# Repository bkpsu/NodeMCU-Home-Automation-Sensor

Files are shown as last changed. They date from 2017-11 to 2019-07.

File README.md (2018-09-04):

# NodeMCU-Home-Automation-Sensor (a.k.a. The Kube)

# IMPORTANT  
Going forward, the Kube sensor will be using the ESPEasy (https://github.com/letscontrolit/ESPEasy) project as firmware. The work done by the ESPEasy team is great and allows me to leverage all of their supported sensors, focusing on hardware development and not wasting redundant effort on software. 

In order to support the OLED screen in ESPEasy (and avoid having non-standard configuration), it is important to move the D9/D10 pins used in the I2C configuration to D3/D4 (SDA/SCL).

# 

Code for Thingiverse item https://www.thingiverse.com/thing:2539897 (The Kube - a NodeMCU/DHT22 based MQTT temp/humidity sensor with local OLED display)

Note: The parts list I posted on the Thingiverse site (and below) contains affiliate links to Amazon. These are the parts I've used/tested in building my sensors, and if you wish to support my designs, please go ahead and use them to order parts. Thank you and enjoy!

Demo & Overview (https://www.youtube.com/watch?v=VefbT6RuT-4)

# Parts List

  *3D printed enclosure (https://www.thingiverse.com/thing:2539897)  
  *OLED screen (http://amzn.to/2xR4iQP) - I2C recommended  
  *NodeMCU breakout board (https://www.tindie.com/products/11677/)  
  *NodeMCU ESP8266 dev board v0.9 (http://amzn.to/2hd6RJk) or 1.0 (http://amzn.to/2ymAkak).  
  *DHT-22 sensor (http://amzn.to/2ymmODK)  
  *headers (http://amzn.to/2fNe81C)  
  *solid hook-up wire, 22awg (https://amzn.to/2voliAb)

# Build Procedure

Initial Build

1. Print enclosure and cover
2. Solder left/right inner headers onto the OSHPark carrier board (15 pins each)
3. Solder DHT22 sensor onto board, with openings facing out
4. Stick NodeMCU board onto carrier board, USB connector facing opposite from DHT22
5. De-pin OLED screen (cut the black plastic holding pins together, remove pins one by one) <- alternatively, you can use breadboard wires (http://amzn.to/2fDGqeJ) with connectors on each end if you don't want to de-pin, but you'll have to bend the OLED screen pins to the side.
6. Cut seven (7) short (~2 inch) lengths of hook-up wire and strip on each end.
7. Connect/solder OLED screen to carrier board as follows:

For SPI OLED:

| Board | Wire Color | OLED  |  
|:---:|:-----:|:-----:|
| 3v3 |  Red | VCC| 
| Gnd |  Black  | Gnd |  
| D10 |  Orange |  Res |  
| D9 |  Gray  |  DC  |  
| D8 |  White  |  CS  |  
| D7 | Yellow  | D1  |  
| D5 | Brown  |  D0  |  

For I2C OLED:



| Board | Wire Color | OLED  |  
|:---:|:-----:|:-----:|
| 3v3 |  Red | VCC| 
| Gnd |  Black  | Gnd | 
| D4 | Blue | SCL |
| D3 | Green | SDA |  

Final Assembly:

1. Stick OLED screen onto mounting posts (ensuring the screen is within the enclosure opening) and use a soldering iron to melt the posts over it.

2. Put NodeMCU carrier board in, ensuring it fits snugly (DHT sensor is tightly within its opening, USB connector is visible)

3. Put enclosure cover on, and secure with small screws (or glue in place)

Hardware Build Video (https://www.youtube.com/watch?v=fA91LcJRbhI)

**Note** Since the video was posted, I've switched to using pins D3/D4 as SCL/SDA for the I2C OLED screen, instead of D9/D10. Please connect the OLED as per the I2C table above!

# Program sensor

Just follow the video below to program the sensor in Arduino IDE using the code provided in this repository.

**Note** Since this video was posted, I updated the code to use the WiFiManager library and allow the ESP8266 to create its own access point (AP). This means you no longer have to specify the Wifi SSID or password in the code. Simply load the code onto the ESP8266, power it on, and look for it in your phone's WiFI settings. Once you connect to it, it will handle connecting to your home's Wifi via a web-based process. This takes one step away from the programming procedure, but please still watch the video below to understand how the different options affect the sensor's operation.

**Note 2** Make sure you have the following Arduino Board files and Libraries installed in order to avoid compilation/runtime errors:  
**Board Files**  
ESP8266 by ESP8266 Community (v 2.4.1 or higher)  
**Libraries**  
Adafruit Unified Sensor by Adafruit (v 1.0.2 or higher)  
ArduinoOTA by Ivan Grokhotkov and Miguel Angel Ajo (v 1.0.0 or higher)  
DHT Sensor Library by Adafruit (v 1.3.0 or higher)  
ESP8266 and ESP32 Oled Driver for SSD1306 Display by Daniel Eichhorn, Fabrice Weinberg (v 4.0.0 or higher)  
ESP8266mDNS  
ESP8266WiFi by Ivan Grokhotkov (v 1.0.0 or higher)  
PubSubClient by Nick O'Leary (v 2.6.0 or higher)  
WiFiManager by tzapu (v 0.12.0 or higher)  

**Note 3** As of 9/3/2018, work on this software project is halted, in favor of using ESPEasy as the firmware. I will leave the project file as-is, in case you don't want to move to ESPEasy, but I recommend using ESPEasy since it's actively developed and supports many more sensors already.

Arduino Programming Video (https://img.youtube.com/vi/uDsnqi1Vl4U)

# Connect to openHAB and Calibrate

Now that we have the sensor built and running, we have to connect it to openHAB - watch the following video on how to do that using the provided MQTT topics, and how to calibrate the sensor by charting its readings against another sensor, thermostat, temperature gauge, etc..

openHAB connection video

That's it! Enjoy the sensor and please contribute to its further design by opening new issues or comments in this repository!

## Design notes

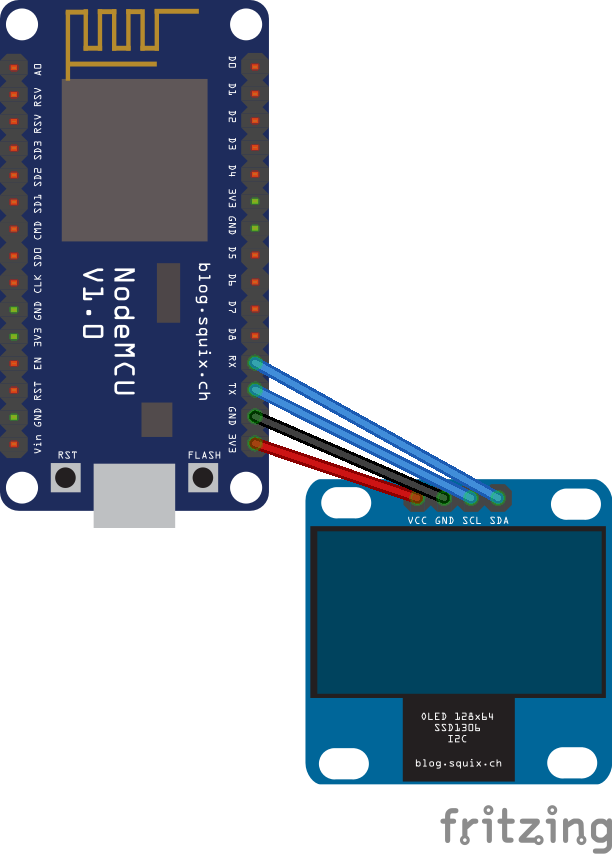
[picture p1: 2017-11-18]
OLED I2C Hookup.png

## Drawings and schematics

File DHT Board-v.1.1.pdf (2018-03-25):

# 15 DHT

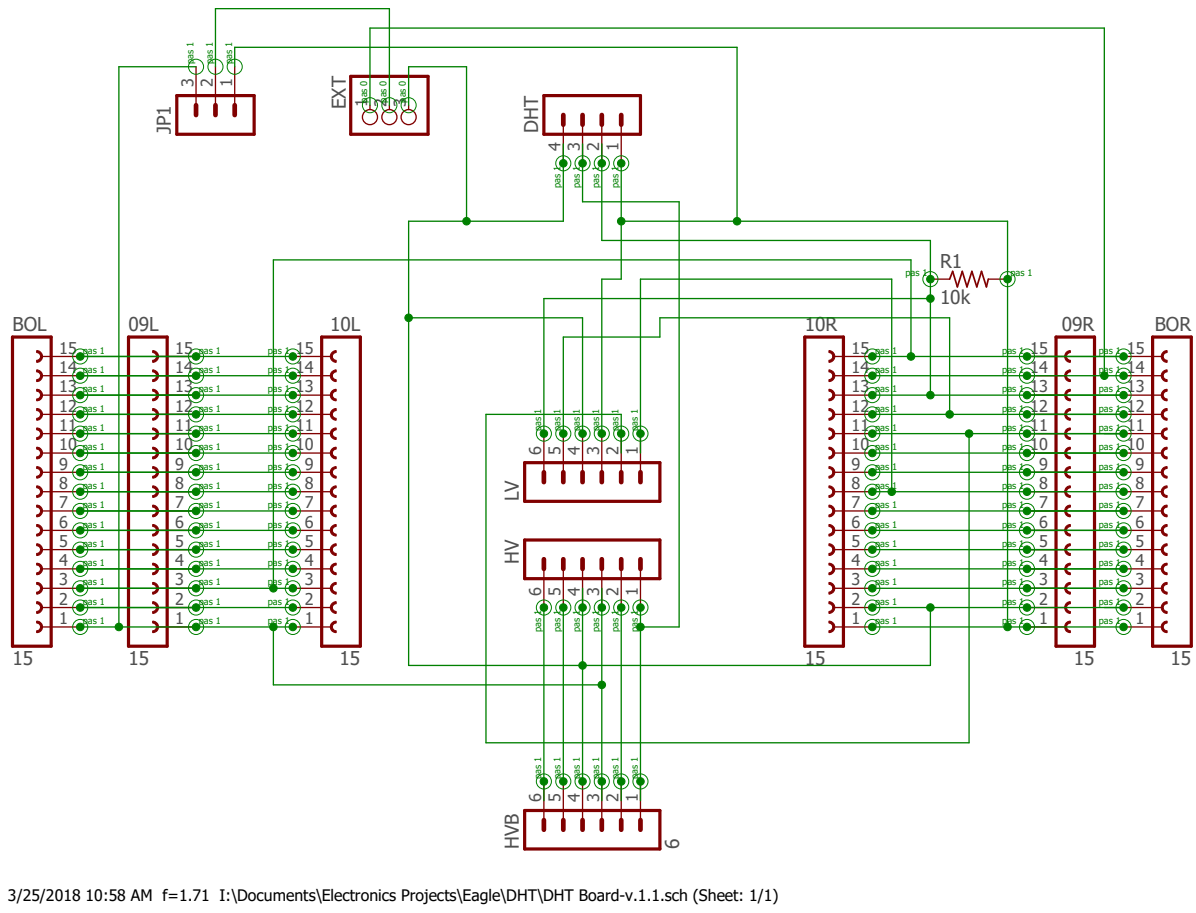
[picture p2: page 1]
BOR; BOL; 1 HVB; 15 EXT 1; pas 1; pas 1 pas 1; pas 0; pas 0 pas 1

3/25/2018 10:58 AM f=1.71 I:\Documents\Electronics Projects\Eagle\DHT\DHT Board-v.1.1.sch (Sheet: 1/1)

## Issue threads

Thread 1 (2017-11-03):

Celcius

samabsalom, 2017-11-03:
great project thanks! however, could you help me turn the display into Celsius, please?
Sam

bkpsu, 2017-11-05:
@samabsalom I just committed a new version of the code, with a new compiler directive (#CELSIUS). I've tried it and it appears to work. Test it and let me know, thanks for submitting the issue!

samabsalom, 2017-11-06:
Hello,
Thanks for getting back to me so quick. started fresh with your new code and ran into problems compiling.
it said
 C:\Users\Sam_A\Desktop\NodeMCU-Home-Automation-Sensor-master\ESP8266-PIR-OLED-Arduino\ESP8266-PIR-OLED-Arduino.ino: In function 'void loop()':

ESP8266-PIR-OLED-Arduino:243: error: too few arguments to function 'void drawDHT(float, float, float, float)'

       drawDHT(h,t,f);

                    ^

C:\Users\Sam_A\Desktop\NodeMCU-Home-Automation-Sensor-master\ESP8266-PIR-OLED-Arduino\ESP8266-PIR-OLED-Arduino.ino:136:6: note: declared here

 void drawDHT(float h, float t, float f, float p)

      ^

Multiple libraries were found for "SSD1306.h"
 Used: C:\Users\Sam_A\Documents\Arduino\libraries\ESP8266_Oled_Driver_for_SSD1306_display
 Not used: C:\Users\Sam_A\Documents\Arduino\libraries\arduino_941869
exit status 1
too few arguments to function 'void drawDHT(float, float, float, float)'

if I removed the ,float p and the ,p from both lines it compiled and uploaded to my board and output a sensible temperature

Thanks very much! I'm going to try to add OTA to it. I'll let you know how I get on!

bkpsu, 2017-11-07:
Ah, my mistake! I am working on incorporating a pressure sensor input, and I uploaded half-finished code for that. Line 243 is missing the pressure input.

OTA would be cool and very useful! If you do end up adding it/making it work, l would appreciate if you forked/added a pull request! I will open a new issue for that.

Closed 2017-11-07.

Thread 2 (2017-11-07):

Add OTA firmware update

bkpsu, 2017-11-07:
It would be great to have the ability to OTA update these sensors wherever they are installed around the house.

samabsalom, 2017-11-07:
Just sent a PR for this. Hope it works for you too. I tried to do it in a similar way to the rest of your file

Sam

bkpsu, 2017-11-08:
#5 will fix this.

bkpsu, 2017-11-08:
Implemented, using @samabsalom  #5

Closed 2017-11-08.

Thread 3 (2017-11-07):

Add pressure sensor support

bkpsu, 2017-11-07:
Looking at MPXV7002 differential pressure sensor, for possible use as a static pressure monitor for HVAC systems. Kube would monitor/report static pressure (and possibly calculate CFM) to HA system, for coordination with automated (or manual) register control, to avoid over pressurizing the HVAC system.

MPXV7002 is an analog (5V) sensor, so work needs to be done to test reading the analog input into the ESP8266's ADC input and make sure resolution/readings make sense.

bkpsu, 2018-04-25:
Latest commit adds software support for the MPXV7002 sensor, but initial testing with the sensor (attached in series with a 180Kohm resistor to drop the 0-5V to 0-1V ADC input) shows bad fluctuation of input even at static pressure (both ports on the sensor tied together). Need to look at using external, lower-range sensor with I2C input most likely, or figure out what's causing the erroneous readings (voltage supply or bad sensor?)

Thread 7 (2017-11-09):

Add Frizing wiring diagrams to Readme

bkpsu, 2017-11-09:
Readme file could use a graphical representation of wiring of the OLED screen (both SPI and I2C versions), as well as external sensor wiring setup.

(Eventually, I think the more technical documentation has to be moved into the Wiki instead of being in the Readme).

bkpsu, 2018-04-25:
Closing, as I rewrote the readme with full formatting and links to the YT videos describing build/setup, and added Fritzing diagram for I2C hookup.

Closed 2018-04-25.

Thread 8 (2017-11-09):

Split out configuration into separate source file

bkpsu, 2017-11-09:
With the number of modes available or planned (local/remote, screen/no screen, motion, temp, pressure, LED), the configuration of the sensor is starting to get unwieldy. I think it would be a good idea to split out the config into a separate .h file (config.h), which would only have the #define statements and MQTT/Wifi config (basically, settings the user is expected to change prior to flashing).

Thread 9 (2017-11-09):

Simplify configuration

bkpsu, 2017-11-09:
While it's good to allow all the different permutations of #define options, I think that also makes things confusing (especially as the number of #define options grows). Perhaps there is a way to simplify that, by making some preconfigured "models" of the sensor, with the correct options already set in the header file (once #8 is completed). Or, the other thought is to minimize the number of options available, keeping only the ones that require a choice (Local/Remote, OLED_SPI/I2C, OTA/no OTA, F/C, ...), while the optional sensor/display options will always be turned on (and fail out if unavailable).

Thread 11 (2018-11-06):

pcb

martymoose, 2018-11-06:
hi had a look at your great project
went to buy a pcb on tinde
they wont ship to australia
have you released the board files so i can get one printed here
cheers

bkpsu, 2018-11-08:
NodeMCU v1.2 done and project posted to this repository: https://github.com/bkpsu/NodeMCU-Breakout-Board

I've ordered some test boards from PCBWay, but I'm 99% sure there shouldn't be any problems :)

Closed 2018-11-08.

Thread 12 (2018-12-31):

ESPeasy configuration

stratosgear, 2018-12-31:
Did I miss somewhere posted instructions on how you setup ESPEasy with your configuration?

Or I will have to piece together how to setup everything from the ESPEasy wiki pages?

Thanks for providing such a nice inspiration for aroom multisensor.

bkpsu, 2019-01-02:
I haven't had a chance to update the repository with a generic/sample configuration file yet, or make a how-to video on configuring ESPEasy on the sensor (though I did touch on the topic during one of my recent live streams here: https://youtu.be/OtSEf2v0Zeg ).

While I work on that, I've saved an existing configuration from one of my home sensors, attached here:

[config_Kitchen_U0_Build20103_201919.zip](https://github.com/bkpsu/NodeMCU-Home-Automation-Sensor/files/2719729/config_Kitchen_U0_Build20103_201919.zip)

You should be able to upload this to your Kube, change the Wifi SSID/Password (in the Config tab), fix the IP range settings, and MQTT broker settings in the "Controllers" section. Let me know if this works.

Thanks for the catch, and I'm happy to see my project has been an inspiration!!

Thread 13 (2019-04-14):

Possible temp offset clac issue?

testack18, 2019-04-14:
Hi BK,

Thanks for sharing your excellent project!
I run into an issue and I'm not sure if it is related to the code or whatever. Please take in consideration that I'm newbie in arduino ide and IOT things so this could be easily my fault.

So the issue is it seems the temp offset is not counted as it should on my device. If I print the value to serial before and after the calculation it shows the exact same value:

```
        Serial.println(String(t));
        t = t + ((5 / 9) * temp_offset);
        Serial.println(String(t));

```

Both has at the moment 27 which is much over as it in reality.
I made some test on the code and it seems int devided by int is int (in this case 0) and 0*temp_offset is 0.

So what about 5.0 / 9.0 ?

Thanks in advance!

eugenesilva, 2019-04-14:
Same thing with me. The humidity offset works fine... but the temperature offset is not working in Celsious...

testack18, 2019-04-15:
Try devide float by float: 5.0 / 9.0
That worked for me.

eugenesilva, 2019-04-15:
Thank you testack18...... I will try it later.

eugenesilva, 2019-04-15:
It worked testack18... thank you very much.

bkpsu, 2019-07-09:
Thanks for finding the issue, @testack18 - I committed the fix to the repo, in case others still use the INO.

Closed 2019-07-09.

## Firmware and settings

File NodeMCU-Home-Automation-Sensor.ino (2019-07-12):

//Sketch for "The Kube" sensor, incorporating the ESP8266 with OLED screen, DHT22 sensor, OTA and other external sensors.

//by bkpsu, https://www.thingiverse.com/thing:2539897

#define MQTT_SOCKET_TIMEOUT 120

/************ HARDWARE CONFIG (CHANGE THESE FOR YOUR SENSOR SETUP) ******************/
//#define REMOTE //Uncomment to enable remote sensor functionality (Wifi & MQTT)
//#define OLED_SPI //Uncomment if using SPI OLED screen (assuming I2C otherwise)
//#define CELSIUS //Uncomment if you want temperature displayed in Celsius
//#define DEEP_SLEEP //Uncomment if you want sensor to sleep after every update (Does NOT work with MOTION_ON, LED_ON or OTA_UPDATE which require constant uptime)
//#define FLIP_SCREEN //Uncomment if mounting to wall with USB connector on top
//#define MOTION_ON //Uncomment if using motion sensor
//#define OLED_MOTION //Uncomment if you want screen to turn on only if motion is detected
//#define LED_ON //Uncomment if using as LED controller
//#define PRESS_ON //Uncomment if using as Pressure monitor
#define ANTI_BURNIN //Uncomment if you want the OLED to invert colors every time the sensor is updated (to prevent burnin)
#define OTA_UPDATE //Uncomment if using OTA updates - REMOTE also needs uncommenting and DEEPSLEEP needs to be commented out

/************ WIFI, OTA and MQTT INFORMATION (CHANGE THESE FOR YOUR SETUP) ******************/
//#define wifi_ssid "wifi_ssid" //enter your WIFI SSID
//#define wifi_password "wifi_password" //enter your WIFI Password
#define mqtt_server "openhabianpi" // Enter your MQTT server address or IP.
#define mqtt_device "Kube" //MQTT device for broker and OTA name
#define mqtt_user "" //enter your MQTT username
#define mqtt_password "" //enter your password
#define OTApassword "123" // change this to whatever password you want to use when you upload OTA
/****************************** MQTT TOPICS (change these topics as you wish)  ***************************************/
#define temperaturepub "home/Kube/temperature"
#define humiditypub "home/Kube/humidity"
#define tempindexpub "home/Kube/temperatureindex"
#define motionpub "home/Kube/motion"
#define presspub  "home/Kube/pressure"

/****************************** DHT 22 Calibration settings *************/

float temp_offset = -12.2;
float hum_offset = 14.9;

/**************************************************/

#define DHTPIN 4      // (D2) what digital pin we're connected to (NodeMCU Breakout Board v1.1 or older)
//#define DHTPIN 12      // (D6) what digital pin we're connected to (NodeMCU Breakout Board v1.2)
#define MOTIONPIN 5   // (D1) what digital pin the motion sensor is connected to
#define PRESSPIN A0    // (A0) what analog pin the pressure sensor is connected to

#define DHTTYPE DHT22   // DHT 22/11 (AM2302), AM2321

#include <PubSubClient.h>
#include "DHT.h"
#include <ESP8266WiFi.h>
#include <WiFiManager.h> //testing Wifimanager
#ifdef OLED_SPI
  #include "SSD1306Spi.h" //OLED Lib for SPI version
#else
  #include <Wire.h>  // Only needed for Arduino 1.6.5 and earlier
  #include "SSD1306.h" //OLED Lib for I2C version
#endif

#ifdef OTA_UPDATE && REMOTE
  #include <ESP8266mDNS.h>
  #include <WiFiUdp.h>
  #include <ArduinoOTA.h>
#endif

DHT dht(DHTPIN, DHTTYPE);

unsigned long currentMillis = 60001; //Set so temperature's read on first scan of program
unsigned long previousMillis = 0;
unsigned long interval = 10000;

float h,t,f,p,h2,t2,f2,p2;//Added %2 for error correction
int motionState;

WiFiClient espClient;
PubSubClient client(espClient);

#ifdef OLED_SPI
  SSD1306Spi  display(D10, D9, D8); //RES, DC, CS (SPI Initialization)
#else
  //SSD1306     display(0x3c, 3 /*D9*/, 1 /*D10*/); //WARNING: Using these pins (defined in the Youtube videos and Readme file) will prevent the operation of the USB Serial monitor
  SSD1306     display(0x3c, 0 /*D3*/, 2 /*D4*/); //Recommended Setup: to be able to use the USB Serial Monitor, use the configuration on this line
#endif


void setup() {
  Serial.begin(9600);
  dht.begin();

  #ifdef MOTION_ON
    pinMode(MOTIONPIN, INPUT);
  #endif
  #ifdef PRESS_ON
    //pinMode(PRESSPIN, INPUT);
  #endif

  display.init();

  #ifdef FLIP_SCREEN
    display.flipScreenVertically();
  #endif
  display.setFont(ArialMT_Plain_10);
  display.setTextAlignment(TEXT_ALIGN_LEFT);

  #ifdef REMOTE
    setup_wifi();

    client.setServer(mqtt_server, 1883); //CHANGE PORT HERE IF NEEDED
    #ifdef OTA_UPDATE
       setupOTA();
    #endif
  #else
    WiFi.mode(WIFI_OFF);
  #endif

}

void setupOTA (){
    ArduinoOTA.setPort(8266); // change this is you wish to use a different port
    ArduinoOTA.setHostname(mqtt_device);
    ArduinoOTA.setPassword((const char *)OTApassword);

    ArduinoOTA.onStart([]() {
      Serial.println("Start");
    });
    ArduinoOTA.onEnd([]() {
      Serial.println("\nEnd");
      ESP.restart();
    });
    ArduinoOTA.onProgress([](unsigned int progress, unsigned int total) {
      Serial.printf("Progress: %u%%\r", (progress / (total / 100)));
    });
    ArduinoOTA.onError([](ota_error_t error) {
      Serial.printf("Error[%u]: ", error);
      if (error == OTA_AUTH_ERROR) Serial.println("Auth Failed");
      else if (error == OTA_BEGIN_ERROR) Serial.println("Begin Failed");
      else if (error == OTA_CONNECT_ERROR) Serial.println("Connect Failed");
      else if (error == OTA_RECEIVE_ERROR) Serial.println("Receive Failed");
      else if (error == OTA_END_ERROR) Serial.println("End Failed");
    });
    ArduinoOTA.begin();
    Serial.print("OTA running");
}

void setup_wifi() {
  delay(10);
  Serial.println();
  Serial.print("Connecting to ");
//  Serial.println(wifi_ssid);

  //display.drawString(0,0,"Wifi: " + String(wifi_ssid));
  //display.display();

  //WiFi.mode(WIFI_STA);
  //WiFi.begin(wifi_ssid, wifi_password);
  ////WiFi.printDiag(Serial);
  //while (WiFi.status() != WL_CONNECTED) {
  //  delay(500);
  //  Serial.print(".");
  //}

  Serial.println("");
  Serial.println("WiFi connected");
  Serial.println("IP address: ");
  Serial.println(WiFi.localIP());

  //display.setTextAlignment(TEXT_ALIGN_RIGHT);
  //display.drawString(120,10, "OK");
  //display.setTextAlignment(TEXT_ALIGN_LEFT);
  //display.drawString(0,20, "IP: " + WiFi.localIP());
  //display.display();

  WiFiManager wifiManager;
  wifiManager.autoConnect("AutoConnectAP");
}

void drawDHT(float h, float t, float f, float p)
{
  display.setFont(ArialMT_Plain_10);
  display.setTextAlignment(TEXT_ALIGN_LEFT);
  display.drawString(0,0, String(mqtt_device));
  display.setFont(ArialMT_Plain_24);
  display.setTextAlignment(TEXT_ALIGN_CENTER);
  #ifdef CELSIUS
    display.drawString(60,18, String(t,1) + " *C");
  #else
    display.drawString(60,18, String(f,1) + " *F");
  #endif
  display.setFont(ArialMT_Plain_10);
  #ifdef PRESS_ON
    display.setTextAlignment(TEXT_ALIGN_LEFT);
    display.drawString(0,40,"Prs: ");
    display.setTextAlignment(TEXT_ALIGN_RIGHT);
    display.drawString(120,40, String(p) + "i");
  #endif
  display.setTextAlignment(TEXT_ALIGN_LEFT);
  display.drawString(0,50,"Hum: ");
  display.setTextAlignment(TEXT_ALIGN_RIGHT);
  display.drawString(120,50, String(h,1) + " %");
}

void loop() {
  #ifdef REMOTE && OTA_UPDATE
  ArduinoOTA.handle();
  #endif

  char strCh[10];
  String str;
  #ifdef REMOTE
    if (!client.loop()) {
      reconnect();
    }
  #endif

  if(currentMillis - previousMillis > interval) {
      previousMillis = currentMillis;

      h = dht.readHumidity();
      // Read temperature as Celsius (the default)
      t = dht.readTemperature();
      // Read temperature as Fahrenheit (isFahrenheit = true)
      f = dht.readTemperature(true);

      // Read pressure (if external pressure sensor connected)
      p = analogRead(PRESSPIN);
      p = ((p/1023)*16.6246)-8.3123; //Convert analog value from MPXV7002 differential pressure sensor to psi range (-8...8 in/h2O) via formula ((ain/max_analog)*full range)-offset

      // Check if any reads failed and exit early (to try again).
      if (isnan(h) || isnan(t) || isnan(f)) {
        Serial.println("Failed to read from DHT sensor!");
        //h=t=f=-1;
        t=t2;//Writes previous read values if the read attempt failed
        f=f2;
        h=h2;
        
      }
      else { //add offsets, if any
        t = t + ((5.0 / 9.0) * temp_offset);
        f = f + temp_offset;
        h = h + hum_offset;
        h2=h;//Store values encase next read fails
        t2=t;
        f2=f;
      }

      // Compute heat index in Fahrenheit (the default)
      float hif = dht.computeHeatIndex(f, h);
      // Compute heat index in Celsius (isFahreheit = false)
      float hic = dht.computeHeatIndex(t, h, false);

      #ifdef REMOTE
        #ifdef CELSIUS
          str = String(t,1);
        #else
          str = String(f,1);
        #endif
        str.toCharArray(strCh,9);
        client.publish(temperaturepub, strCh);
        str = String(h,1);
        str.toCharArray(strCh,9);
        client.publish(humiditypub, strCh);
        #ifdef CELSIUS
          str = String(hic,2);
        #else
          str = String(hif,2);
        #endif
        str.toCharArray(strCh,9);
        client.publish(tempindexpub, strCh);
        client.loop();
        str = String(p,2);
        str.toCharArray(strCh,9);
        client.publish(presspub, strCh);
      #endif

      Serial.print("Humidity: ");
      Serial.print(h,1);
      Serial.print(" %\t");
      Serial.print("Temperature: ");
      Serial.print(t,1);
      Serial.print(" *C ");
      Serial.print(f,1);
      Serial.print(" *F\t");
      Serial.print("Heat index: ");
      Serial.print(hic,1);
      Serial.print(" *C ");
      Serial.print(hif,1);
      Serial.println(" *F");
      Serial.print(p,1);
      Serial.println(" in/H2O");
#ifdef ANTI_BURNIN
      display.invertDisplay();
      display.display();
#endif
      display.clear();
      display.normalDisplay();
#ifdef OLED_MOTION //Clears display on each loop if OLED Motion is active, otherwise prints display as usual
      display.clear();
#else
      drawDHT(h,t,f,p);
#endif  
      display.display();
  }
  currentMillis = millis();

#ifdef MOTION_ON
  motionState = digitalRead(MOTIONPIN);
//   print out the state of the button:
  if (motionState == 1)
{
    Serial.println("Motion Event:");
    #ifdef REMOTE
      client.publish(motionpub, "1");
      client.loop();
    #endif
    display.setTextAlignment(TEXT_ALIGN_RIGHT);
    display.drawString(120,0, "M");
    #ifdef OLED_MOTION//Writes the whole display if motion is sensed, otherwise just the "M"
    drawDHT(h,t,f,p);
    #endif
    display.display();
    delay (10000);
    display.clear();
    drawDHT(h,t,f,p);
    display.display();
  }
#else
  #ifdef DEEP_SLEEP
    #ifndef OTA
      ESP.deepSleep(60000000,WAKE_RF_DEFAULT);   //If a motion sensor is not being used, we can put ESP into deep-sleep to save energy/wifi channel
    #endif
  #endif
#endif
}


void reconnect() {
  // Loop until we're reconnected
  while (!client.connected()) {
    Serial.print("Attempting MQTT connection...");
    //display.drawString(0,30, "MQTT: ");
    //display.display();

    // Attempt to connect
  if (client.connect(mqtt_device, mqtt_user, mqtt_password)) {
      Serial.println("connected");
      //display.setTextAlignment(TEXT_ALIGN_RIGHT);
      //display.drawString(120,40, "OK");
      //display.display();

      client.subscribe(temperaturepub);
      client.subscribe(humiditypub);
      client.subscribe(tempindexpub);
      client.subscribe(motionpub);
      client.subscribe(presspub);
    } else {
      Serial.print("failed, rc=");
      Serial.print(client.state());
      Serial.println(" try again in 5 seconds");
      // Wait 5 seconds before retrying
      delay(10000);
    }
  }
}

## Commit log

2017-09-29 Added configuration options, cleaned up code
    -Added hardware config options/compiler directives for different sensor/hardware configs (OLED SPI/I2C, Motion sensor, Deep Sleep, ...).
    -Cleaned up code to show all config options up top
    -Added Deep Sleep and Motion Sensor functionality (motion sensor shows "M" in top right corner of display if fired off).
2017-10-04 LOCAL config, offset calibration
    -Add LOCAL config option, disabling Wifi/MQTT (for localy display only)
    -Add sensor calibration (offset) values, to allow for fixing the wild variety of DHT22 sensors out there
2017-10-15 Fixed I2C connection typo
    SCL/SDA lines were reversed
2017-10-15 Changed link to OSHPark board
    Modified to the new board revision.
2017-11-05 Fix Issue #1 (Celsius)
    Added option to display temperature in Celsius on OLED
2017-11-23 Changed file name to allow easier clone/use of Arduino IDE
2017-11-26 Added source Fritzing diagram for OLED hookup
    [OLED Hookup.fzz]
2018-03-25 2018/03/25(BK): Added schematic PDF
2018-04-25 2018/04/24(BK): Adds Wifimanager support (for easy connection of sensor to Wifi network) and initial support for external pressure sensors (work in progress)
2018-06-06 Add configuration option for anti-burning
    Added the #ANTI_BURNIN compiler directive to make screen inversion optional between refreshes, per request from one of the Youtube viewers.
    [NodeMCU-Home-Automation-Sensor.ino]
2018-07-22 Added code to enabled OLED_motion, masks DHT sensors read errors with previous read values, reduced output Significant Figures so graphing is more accurate, and changed the min config so the serial o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
    To enable the OLED_motion option I added an if statement in the main loop so it writes the display if its not enabled, or clears it if it is. Then added a write function to Motion section that write the display if its enabled, or just the M if not.
    Changed code to report previous read good values from DHT on sensor read errors. The quality of these sensors very, and the temperatures should not be changing that much with these read frequencies. So I added var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
    [NodeMCU-Home-Automation-Sensor.ino]
2018-07-22 Modified ino file to note USB Serial monitor pin interference and modified Readme to list board/library files required for programming.
    [NodeMCU-Home-Automation-Sensor.ino]
2018-09-04 Updated Readme to fix I2C connections and recommend ESPEasy
    [NodeMCU-Home-Automation-Sensor.ino]
2019-01-02 Added sample ESPEasy Configuration file
    Added a sample ESPEasy configuration file, for a Kitchen Kube sensor, with DHT22 and OLED screen configration embedded. The user can upload this file to their newly built Kube sensor, change the Wifi/IP/MQTT broker settings, and that should allow the sensor to work within the user's HA system.
2019-01-21 2019/01/21(BK): Added ESP_Easy sample configuration file (config.dat).
2019-01-21 2019/01/21(BK): Removed "kitchen" sensor config file, since config.dat is directly uploadable to an ESPEasy node.
2019-07-09 Fix temp offset in C as found in #13
    Fixes #13 (using integer division instead of float, resulting in 0 offset regardless of offset value).
    [NodeMCU-Home-Automation-Sensor.ino]
2019-07-11 Added DHTPin 12 as an option in the Arduino sketch. The option is commented out and specifies that this is the pin to be used with the NodeMCU Breakout board version 1.2. Additionally, the previous c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
